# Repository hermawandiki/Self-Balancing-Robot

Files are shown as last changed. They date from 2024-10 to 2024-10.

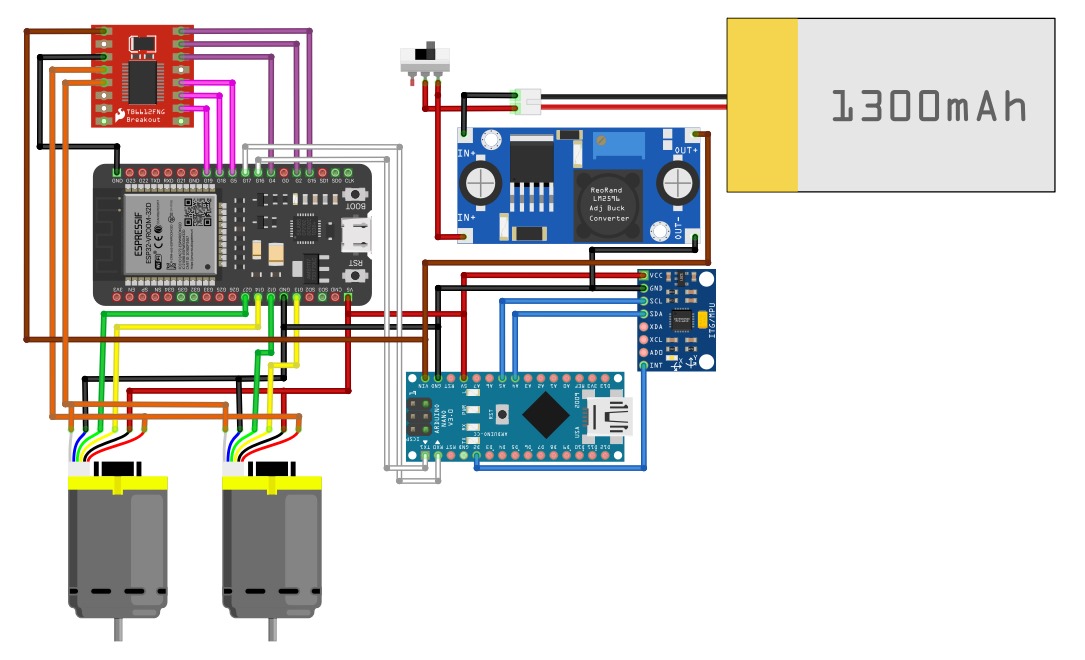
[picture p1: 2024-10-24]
Hardware/WhatsApp Image 2024-08-28 at 14.37.04_eb7606b8.jpg

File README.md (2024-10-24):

# Self-Balancing-Robot

Diki Hermawan - 4122600037
****
Mata Kuliah : Proyek Robotika
****
Dosen Pengampu : Eko Henfri Binugroho, S. S.T., M. Eng.
****
Semester 5 - Teknik Mekatronika

Politeknik Elektronika Negeri Surabaya

2024

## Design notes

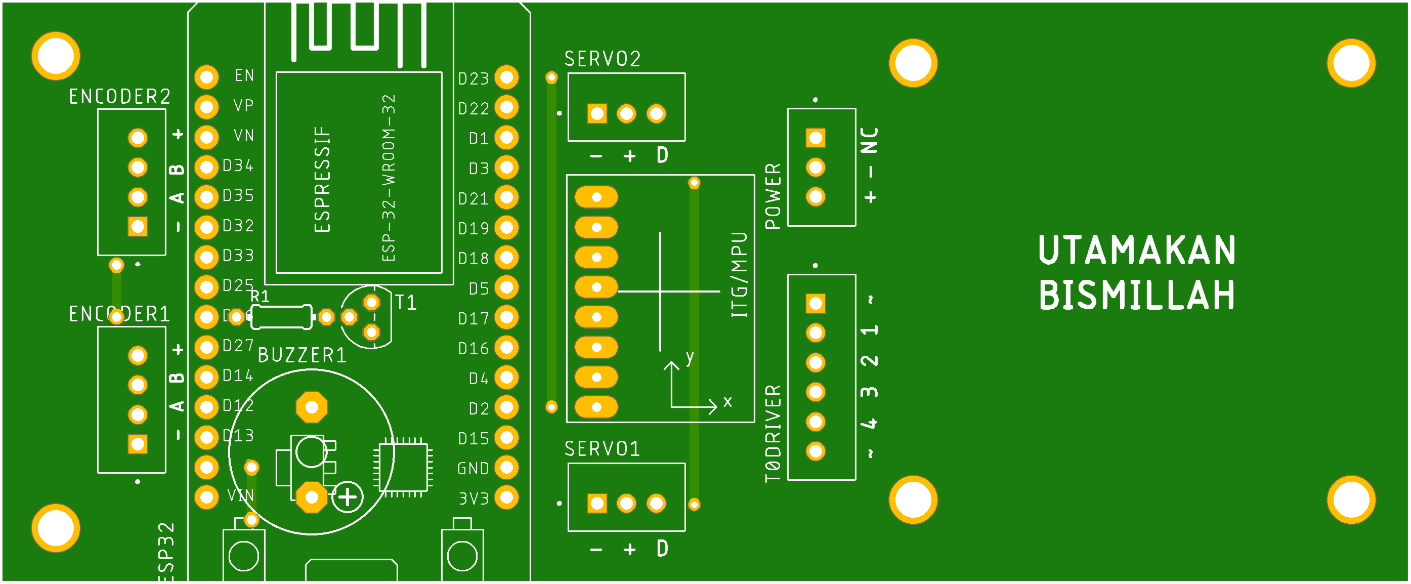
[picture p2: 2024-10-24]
Hardware/_Top.png

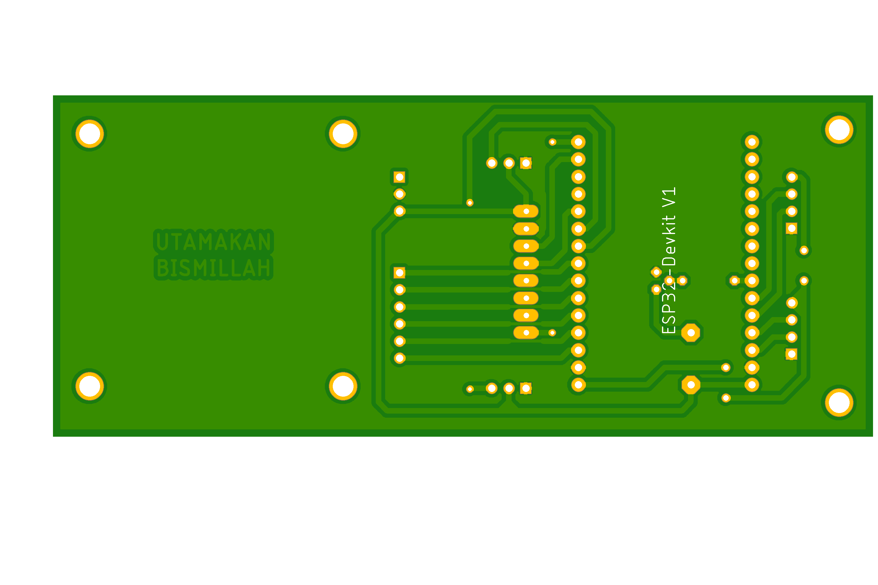
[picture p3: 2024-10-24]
Hardware/Bottom.png

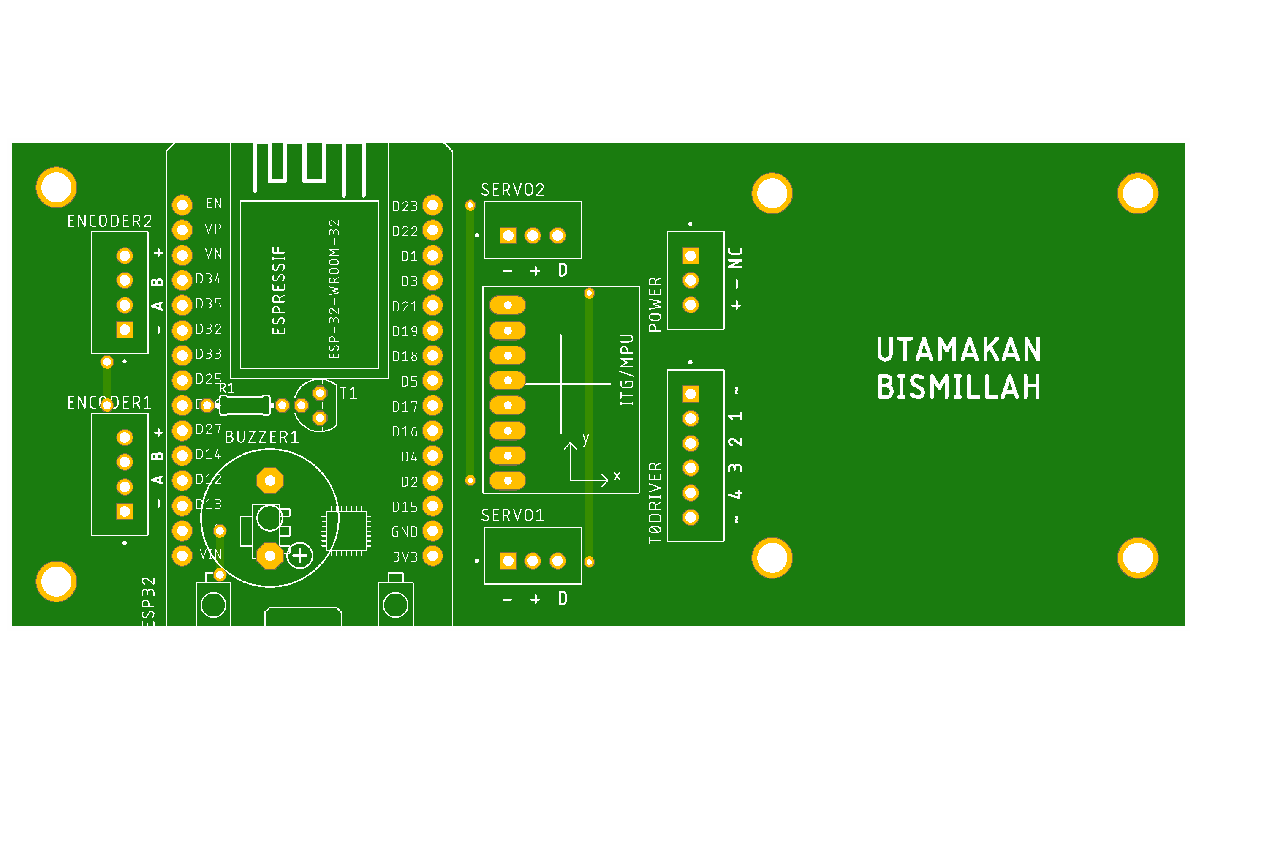
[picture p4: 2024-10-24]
Hardware/Top.png

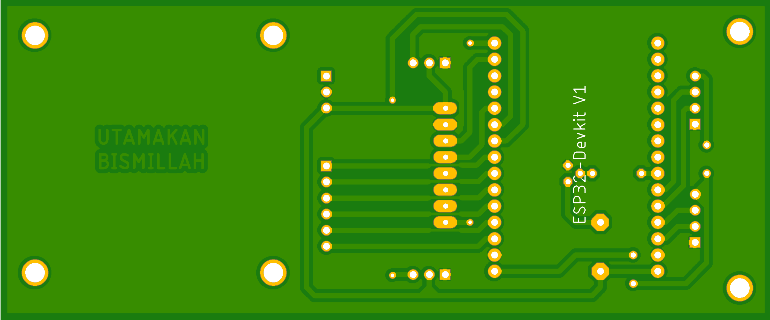
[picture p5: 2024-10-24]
Hardware/_Bottom.png

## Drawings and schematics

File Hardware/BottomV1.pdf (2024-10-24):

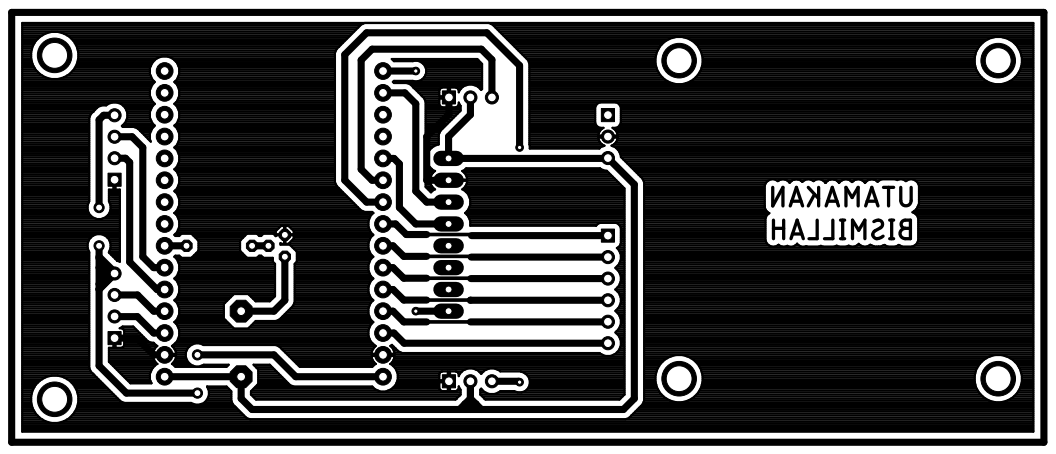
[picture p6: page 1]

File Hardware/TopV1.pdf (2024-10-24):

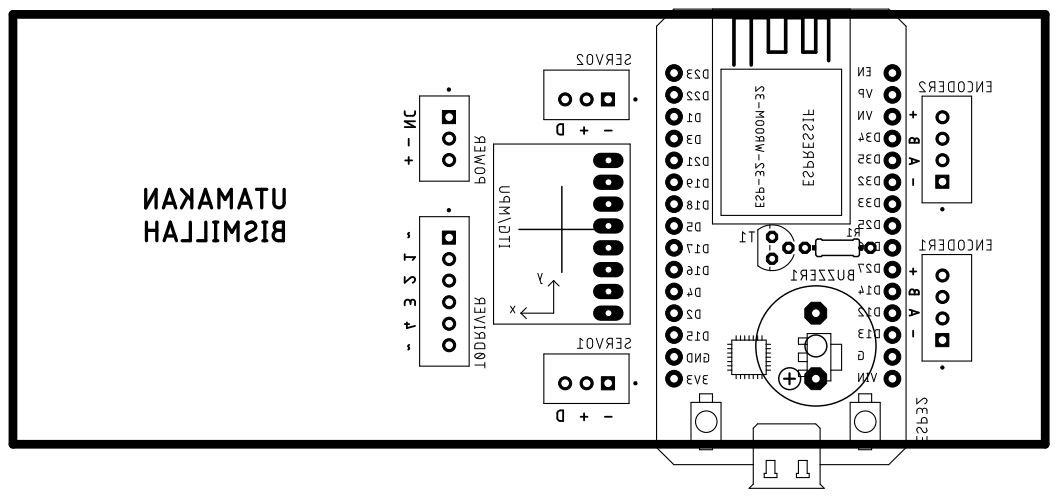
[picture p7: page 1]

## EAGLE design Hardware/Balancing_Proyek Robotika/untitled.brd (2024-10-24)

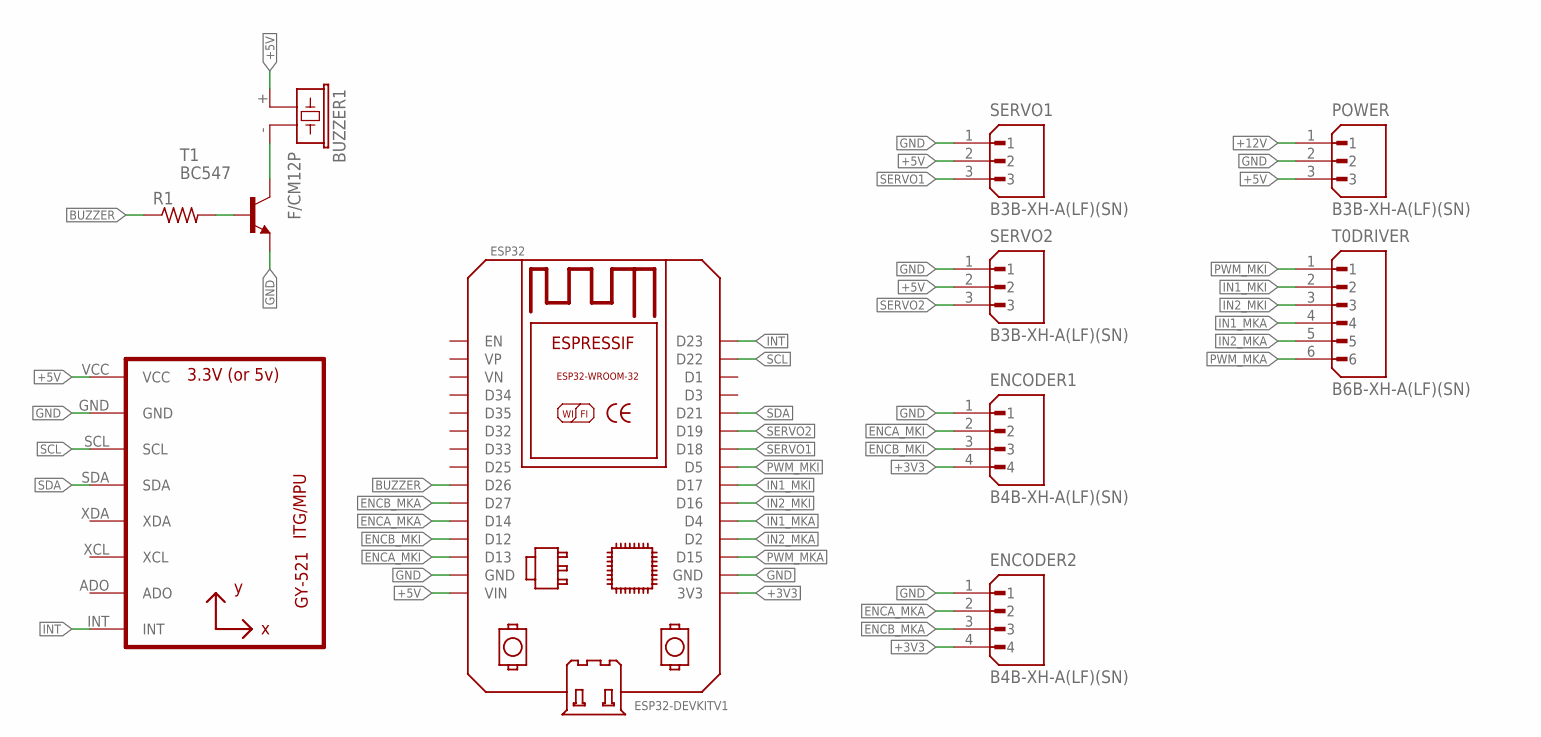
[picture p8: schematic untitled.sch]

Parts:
BUZZER1: F/CM12P
ENCODER1, ENCODER2: B4B-XH-A(LF)(SN); JST_B4B-XH-A(LF)(SN)
ESP32: ESP32DEVKITV1; ESP32-DEVKITV1
POWER: B3B-XH-A(LF)(SN); JST_B3B-XH-A(LF)(SN)
R1: R-US_0204/7; 0204/7
SERVO1, SERVO2: B3B-XH-A(LF)(SN); JST_B3B-XH-A(LF)(SN)
T0DRIVER: B6B-XH-A(LF)(SN); JST_B6B-XH-A(LF)(SN)
T1: BC547; TO92
U2: GY-521MPU6050; GY-521

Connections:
+3V3: ENCODER1.4, ENCODER2.4, ESP32.3V3
+5V: BUZZER1.+ (1), ESP32.VIN, POWER.3, SERVO1.2, SERVO2.2, U2.VCC
+12V: POWER.1
BUZZER: ESP32.D26, R1.1
ENCA_MKA: ENCODER2.2, ESP32.D14
ENCA_MKI: ENCODER1.2, ESP32.D13
ENCB_MKA: ENCODER2.3, ESP32.D27
ENCB_MKI: ENCODER1.3, ESP32.D12
GND: ENCODER1.1, ENCODER2.1, ESP32.GND, ESP32.GND@1 (GND), POWER.2, SERVO1.1, SERVO2.1, T1.1 (E), U2.GND
IN1_MKA: ESP32.D4, T0DRIVER.4
IN1_MKI: ESP32.D17, T0DRIVER.2
IN2_MKA: ESP32.D2, T0DRIVER.5
IN2_MKI: ESP32.D16, T0DRIVER.3
INT: ESP32.D23, U2.INT
unnamed: BUZZER1.- (2), T1.3 (C)
unnamed: R1.2, T1.2 (B)
PWM_MKA: ESP32.D15, T0DRIVER.6
PWM_MKI: ESP32.D5, T0DRIVER.1
SCL: ESP32.D22, U2.SCL
SDA: ESP32.D21, U2.SDA
SERVO1: ESP32.D18, SERVO1.3
SERVO2: ESP32.D19, SERVO2.3

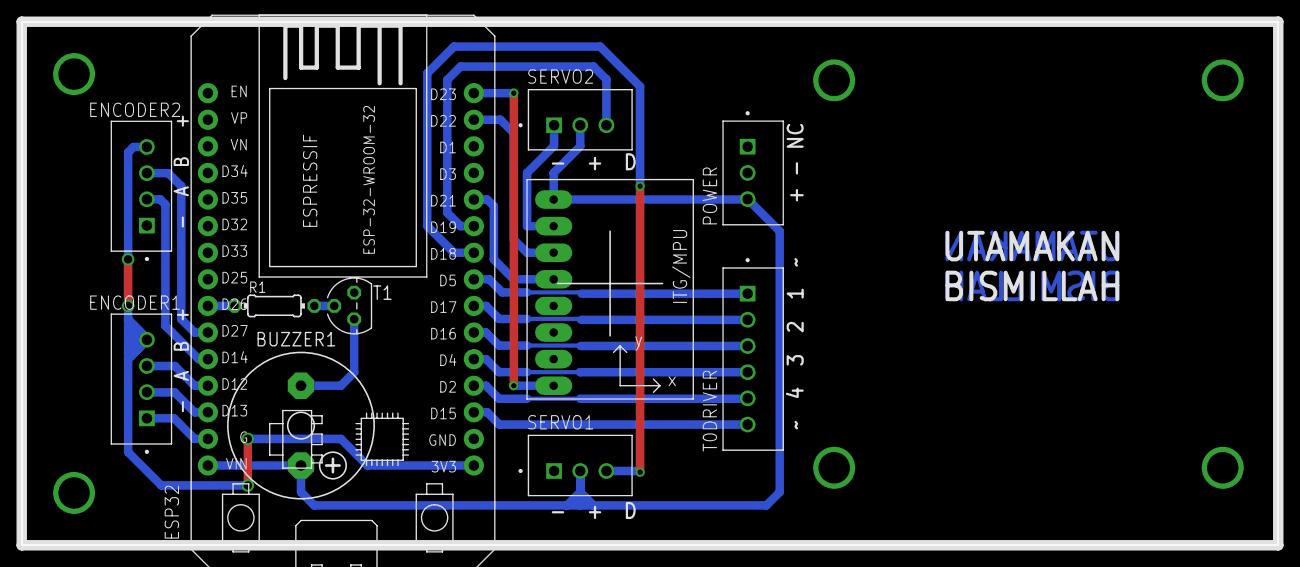
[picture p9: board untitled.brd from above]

Board: 2 copper layers, 120.0 x 50.0 mm, 11 parts (0 on the bottom side), 21 nets.

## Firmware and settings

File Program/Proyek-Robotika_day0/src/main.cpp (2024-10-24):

#include <Arduino.h>
#include <BluetoothSerial.h>
#include <ESP32Servo.h>
#include <ESP32Encoder.h>
#include "I2Cdev.h"
#include "MPU6050_6Axis_MotionApps20.h"
#include "Wire.h"
#include "math.h"

#define ENCA_MKa 13
#define ENCB_MKa 12
#define ENCA_MKi 14
#define ENCB_MKi 27

#define IN1_MKa 15
#define IN2_MKa 2
#define PWM_MKa 4

#define IN1_MKi 16
#define IN2_MKi 17
#define PWM_MKi 5

#define ServoPin1 18
#define ServoPin2 19

BluetoothSerial blutut;
MPU6050 mpu;
Servo servo1, servo2;
ESP32Encoder encoder_MKa;
ESP32Encoder encoder_MKi;

const int PWM_CHANNEL_MKa = 2;
const int PWM_CHANNEL_MKi = 3;
const int PWM_FREQ = 30000;
const int PWM_RESOLUTION = 8;
const int PWM_MAX_DUTY = (int)(pow(2, PWM_RESOLUTION) - 1);

#define INTERRUPT_PIN 23
#define LED_PIN 2
bool blinkState = false;

bool dmpReady = false;
uint8_t mpuIntStatus;
uint8_t devStatus;
uint16_t packetSize;
uint16_t fifoCount;
uint8_t fifoBuffer[64];

Quaternion q;
VectorInt16 aa;
VectorInt16 aaReal;
VectorInt16 aaWorld;
VectorFloat gravity;

float euler[3];
float ypr[3];
uint8_t teapotPacket[14] = { '$', 0x02, 0, 0, 0, 0, 0, 0, 0, 0, 0x00, 0x00, '\r', '\n' };
volatile bool mpuInterrupt = false;
void dmpDataReady() {
    mpuInterrupt = true;
}

unsigned int Yaw, Pitch, Roll;
char buffRx;
bool flag = 0, konek = 0;
long lastTime = 0;
uint8_t step = 0;

void motor(int pwm1, int pwm2){
  if(pwm1>0){
    digitalWrite(IN1_MKi, HIGH);
    digitalWrite(IN2_MKi, LOW);
  }else{
    digitalWrite(IN1_MKi, LOW);
    digitalWrite(IN2_MKi, HIGH);
  }

  if(pwm2>0){
    digitalWrite(IN1_MKa, HIGH);
    digitalWrite(IN2_MKa, LOW);
  }else{
    digitalWrite(IN1_MKa, LOW);
    digitalWrite(IN2_MKa, HIGH);
  }

  pwm1 = constrain(abs(pwm1) + 10, 10, 255);
  pwm2 = constrain(abs(pwm2) + 10, 10, 255);
  
  ledcWrite(PWM_CHANNEL_MKi, pwm1);
  ledcWrite(PWM_CHANNEL_MKa, pwm2);
}

void setup() {
  Wire.begin();
  Wire.setClock(400000);
  Serial.begin(115200);
  blutut.begin("Robot Dinasti");

  mpu.initialize();
  pinMode(INTERRUPT_PIN, INPUT);
  devStatus = mpu.dmpInitialize();
  mpu.setXGyroOffset(220);
  mpu.setYGyroOffset(76);
  mpu.setZGyroOffset(-85);
  mpu.setZAccelOffset(1788);

  if(devStatus == 0){
    mpu.CalibrateAccel(6);
    mpu.CalibrateGyro(6);
    mpu.PrintActiveOffsets();
    mpu.setDMPEnabled(true);
    attachInterrupt(digitalPinToInterrupt(INTERRUPT_PIN), dmpDataReady, RISING);
    mpuIntStatus = mpu.getIntStatus();
    dmpReady = true;
    packetSize = mpu.dmpGetFIFOPacketSize();
  } else{
    // ga lapo-lapo
  }

  pinMode(LED_PIN, OUTPUT);

  ESP32PWM::allocateTimer(0);
  ESP32PWM::allocateTimer(1);
  servo1.setPeriodHertz(50);
  servo1.attach(ServoPin1, 500, 2500);
  servo2.setPeriodHertz(50);
  servo2.attach(ServoPin2, 500, 2500);
  
  pinMode(IN1_MKa, OUTPUT);
  pinMode(IN2_MKa, OUTPUT);
  pinMode(IN1_MKi, OUTPUT);
  pinMode(IN2_MKi, OUTPUT);
  ledcSetup(PWM_CHANNEL_MKa, PWM_FREQ, PWM_RESOLUTION);
  ledcSetup(PWM_CHANNEL_MKi, PWM_FREQ, PWM_RESOLUTION);
  ledcAttachPin(PWM_MKa, PWM_CHANNEL_MKa);
  ledcAttachPin(PWM_MKi, PWM_CHANNEL_MKi);

  step = 1;  
}

void loop() {
  if(!dmpReady) return;
  while (!mpuInterrupt && fifoCount < packetSize) {
    if (mpuInterrupt && fifoCount < packetSize) {
      fifoCount = mpu.getFIFOCount();
    }
  }
  mpuInterrupt = false;
  mpuIntStatus = mpu.getIntStatus();
  fifoCount = mpu.getFIFOCount();
  if (fifoCount < packetSize) {}
  else if ((mpuIntStatus & (0x01 << MPU6050_INTERRUPT_FIFO_OFLOW_BIT)) || fifoCount >= 1024) {
    mpu.resetFIFO();
  }
  else if (mpuIntStatus & (0x01 << MPU6050_INTERRUPT_DMP_INT_BIT)) {
    while (fifoCount >= packetSize) {
      mpu.getFIFOBytes(fifoBuffer, packetSize);
      fifoCount -= packetSize;
    }

    mpu.dmpGetQuaternion(&q, fifoBuffer);
    mpu.dmpGetGravity(&gravity, &q);
    mpu.dmpGetYawPitchRoll(ypr, &q, &gravity);

    Roll  = (int)(((ypr[2] * 180 / M_PI) + 180.0) + 0.5);
    Pitch = (int)(((ypr[1] * 180 / M_PI) + 180.0) + 0.5);
    Yaw   = (int)(((ypr[0] * 180 / M_PI) + 180.0) + 0.5);

    // blinkState = !blinkState;
    // digitalWrite(LED_PIN, blinkState);
  }

  // ==================================================================== USER CODE BEGIN HERE ====================================================================
  
  Serial.print("Yaw: ");
  Serial.print(Yaw);
  Serial.print(" | Pitch: ");
  Serial.print(Pitch);
  Serial.print(" | Roll: ");
  Serial.println(Roll);

  // if(millis() - lastTime > 1000 && step == 1){
  //   servo1.write(0);
  //   servo2.write(0);
  //   ledcWrite(PWM_CHANNEL_MKi, 150);
  //   ledcWrite(PWM_CHANNEL_MKa, 150);
  //   digitalWrite(IN1_MKa, HIGH);
  //   digitalWrite(IN2_MKa, HIGH);
  //   digitalWrite(IN1_MKi, HIGH);
  //   digitalWrite(IN2_MKi, HIGH);
  //   digitalWrite(LED_PIN, HIGH);
  //   lastTime = millis();
  //   step = 2;
  // }
  // if(millis() - lastTime > 1000 && step == 2){
  //   servo1.write(180);
  //   servo2.write(180);
  //   ledcWrite(PWM_CHANNEL_MKi, 50);
  //   ledcWrite(PWM_CHANNEL_MKa, 50);
  //   digitalWrite(IN1_MKa, LOW);
  //   digitalWrite(IN2_MKa, LOW);
  //   digitalWrite(IN1_MKi, LOW);
  //   digitalWrite(IN2_MKi, LOW);
  //   digitalWrite(LED_PIN, LOW);
  //   lastTime = millis();
  //   step = 1;
  // }

  // ===================================================================== USER CODE END HERE =====================================================================

  // if(blutut.available()){
  //   buffRx = blutut.read();
  //   Serial.println(buffRx);
  // }

  // if(millis() - lastTime > 50){
  //   blutut.print(Yaw);
  //   blutut.print("|");
  //   blutut.print(Pitch);
  //   blutut.print("|");
  //   blutut.print(Roll);
  //   blutut.println("|");
  //   lastTime = millis();
  // }

  // if(blutut.connected() && konek==0){
  //   blutut.println("Enter pin to start!");
  //   konek = 1;
  // }
  // if(!blutut.connected()){
  //   konek = 0;
  //   flag = 0;
  // }

  // if(blutut.available()){
  //   buffRx = blutut.read();
  //   Serial.println(buffRx);
  //   if(buffRx == '~') {
  //     blutut.println("Started...");
  //     flag = 1;
  //   }else {
  //     flag = 0;
  //     blutut.println("Can't start, try again!");
  //   }
  // }
  
  // while(flag){
  //   if(blutut.available()){
  //     buffRx = blutut.read();
  //     Serial.println(buffRx);
  //     if(buffRx == '`') {
  //       blutut.println("Stopped...");
  //       flag = 0;
  //     }
  //   }
  //   if(!blutut.connected()){
  //     konek = 0;
  //     flag = 0;
  //   }
    
  //   // code begin here
  //   if(millis() - lastTime > 1000){
  //     blutut.println("Balancing...");
  //     lastTime = millis();
  //   }
  //   // code end here
  // }
}

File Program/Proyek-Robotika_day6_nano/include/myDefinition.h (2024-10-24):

#ifndef __MYDEFINITION_H__
#define __MYDEFINITION_H__

#include <Arduino.h>

#define DEBUG 0

#if DEBUG == 0
#define debug(x) monitor.print(x);
#define debugln(x) monitor.println(x);
#else
#define debug(x)
#define debugln(x)
#endif

// PID
#define KpPitch 17.0  // 10 // 16 // 16 // 16
#define KdPitch 0.8  // 0.01 // 0.7 // 0.9 / 0.7
#define KiPitch 194.5  // 30 // 77 // 95 // 153

#define KpYaw 14.0
#define KdYaw 0.3
#define KiYaw 20.02

#define KpPos 0.0
#define KdPos 0.0
#define KiPos 0.0

// Motor Driver
#define PWM_MKI 9
#define IN1_MKI A3
#define IN2_MKI A2
#define IN1_MKA A1
#define IN2_MKA A0
#define PWM_MKA 10

// Serial Communication
#define RX_PIN_BT 0
#define TX_PIN_BT 1
#define RX_MONITOR 11
#define TX_MONITOR 12

// MPU6050
#define INT_PIN 4

// Encoder
#define ENCA_MKI 2
#define ENCB_MKI 7
#define ENCA_MKA 3
#define ENCB_MKA 8

// Servo
#define SERVO1_PIN 5
#define SERVO2_PIN 6

// Buzzer
#define BUZZER_PIN 13
#define BuzzOn digitalWrite(BUZZER_PIN, HIGH)
#define BuzzOff digitalWrite(BUZZER_PIN, LOW)
#define BuzzTit(y) {for(uint8_t ii=0; ii<y; ii++){BuzzOn; delay(70); BuzzOff; delay(70);}}

// Global Variable
extern uint8_t lastStateA1, lastStateB1, lastStateA2, lastStateB2;
extern volatile int encoderM1, encoderM2;
extern double spPitch, spYaw;

// Function Prototype
extern void configIO();
extern void motor(int16_t pwm1, int16_t pwm2);
extern void handleEncMki();
extern void handleEncMka();

#endif

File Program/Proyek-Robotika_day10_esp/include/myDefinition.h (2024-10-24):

#ifndef __MYDEFINITION_H__
#define __MYDEFINITION_H__

#include <Arduino.h>

#define DEBUG 1

#if DEBUG == 1
#define debug(x) Serial.print(x);
#define debugln(x) Serial.println(x);
#else
#define debug(x)
#define debugln(x)
#endif

// PID
const double KpPitch = 17.0;  // 10 // 16 // 16 // 16
const double KdPitch = 0.8;  // 0.01 // 0.7 // 0.9 / 0.7
const double KiPitch = 150.5;  // 30 // 77 // 95 // 153

const double KpYaw = 14.0;
const double KdYaw = 0.3;
const double KiYaw = 20.02;

// Motor Driver
#define PWM_MKI 15
#define IN1_MKI 2
#define IN2_MKI 4
#define IN1_MKA 16
#define IN2_MKA 17
#define PWM_MKA 5

#define PWM_MKI_CHANNEL 0
#define PWM_MKA_CHANNEL 1

// MPU6050
#define INT_PIN 23

// Encoder
#define ENCA_MKI 13
#define ENCB_MKI 25 // 12
#define ENCA_MKA 33 // 14
#define ENCB_MKA 27

// Servo
#define SERVO1_PIN 18
#define SERVO2_PIN 19

// Buzzer
#define BUZZER_PIN 26
#define BuzzOn digitalWrite(BUZZER_PIN, HIGH)
#define BuzzOff digitalWrite(BUZZER_PIN, LOW)
#define BuzzTit(y) {for(uint8_t ii=0; ii<y; ii++){BuzzOn; delay(70); BuzzOff; delay(70);}}

// Global Variable
extern uint8_t lastStateA1, lastStateB1, lastStateA2, lastStateB2;
extern volatile long encoderM1, encoderM2;

// Function Prototype
extern void configIO();
extern void motor(int16_t pwm1, int16_t pwm2);
extern void handleEncMki();
extern void handleEncMka();

#endif

////// Recommended servo pins include 2,4,12-19,21-23,25-27,32-33
/*
** ledc: 0  => Group: 0, Channel: 0, Timer: 0
** ledc: 1  => Group: 0, Channel: 1, Timer: 0
** ledc: 2  => Group: 0, Channel: 2, Timer: 1
** ledc: 3  => Group: 0, Channel: 3, Timer: 1
** ledc: 4  => Group: 0, Channel: 4, Timer: 2
** ledc: 5  => Group: 0, Channel: 5, Timer: 2
** ledc: 6  => Group: 0, Channel: 6, Timer: 3
** ledc: 7  => Group: 0, Channel: 7, Timer: 3
** ledc: 8  => Group: 1, Channel: 8, Timer: 0
** ledc: 9  => Group: 1, Channel: 9, Timer: 0
** ledc: 10 => Group: 1, Channel: 10, Timer: 1
** ledc: 11 => Group: 1, Channel: 11, Timer: 1
** ledc: 12 => Group: 1, Channel: 12, Timer: 2
** ledc: 13 => Group: 1, Channel: 13, Timer: 2
** ledc: 14 => Group: 1, Channel: 14, Timer: 3
** ledc: 15 => Group: 1, Channel: 15, Timer: 3
*/

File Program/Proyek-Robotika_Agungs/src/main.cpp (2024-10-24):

#include <Arduino.h>
#include "PID_v1.h"
#include "MPU6050_6Axis_MotionApps20.h"
#include "Wire.h"
#include "ESP32Encoder.h"

MPU6050 mpu;
bool blinkState = false;
bool dmpReady = false;
uint8_t mpuIntStatus;
uint8_t devStatus;
uint16_t packetSize;
uint16_t fifoCount;
uint8_t fifoBuffer[64];
Quaternion q;
VectorFloat gravity;
float euler[3];
float ypr[3];
volatile bool mpuInterrupt = false;
void dmpDataReady() {
  mpuInterrupt = true;
}
int Yaw, Pitch, Roll;

double originalSetpoint = 180.0;
double setpointPitch = originalSetpoint;
double setpointYaw = originalSetpoint;
double movingAngleOffset = 0.1;
double inputPitch, outputPitch, inputYaw, outputYaw;

double KpPitch = 17; // 10 // 16 // 16 // 16
double KdPitch = 0.8; // 0.01 // 0.7 // 0.9 / 0.7
double KiPitch = 194.5; // 30 // 77 // 95 // 153
PID pidPitch(&inputPitch, &outputPitch, &setpointPitch, KpPitch, KiPitch, KdPitch, DIRECT);
double KpYaw = 14;
double KdYaw = 0.3;
double KiYaw = 20.02;
PID pidYaw(&inputYaw, &outputYaw, &setpointYaw, KpYaw, KiYaw, KdYaw, DIRECT);

ESP32Encoder encM1, encM2;
uint8_t pinMotor[] = {15, 2, 4, 16, 17, 5};
void motor(int16_t pwm1, int16_t pwm2){
  if(pwm1>0){
    digitalWrite(2, HIGH);
    digitalWrite(4, LOW);
  }else{
    digitalWrite(2, LOW);
    digitalWrite(4, HIGH);
  }

  if(pwm2>0){
    digitalWrite(16, LOW);
    digitalWrite(17, HIGH);
  }else{
    digitalWrite(16, HIGH);
    digitalWrite(17, LOW);
  }

  pwm1 = constrain(abs(pwm1), 0, 255); // 0
  pwm2 = constrain(abs(pwm2)+10, 10, 255); // 10
  
  ledcWrite(0, pwm1);
  ledcWrite(1, pwm2);
}
//
uint8_t i;

void setup(){
  Wire.begin();
  Wire.setClock(400000);
  Serial.begin(9600);
  for(int i=0; i<6; i++){
    pinMode(pinMotor[i], OUTPUT);
  }

  ledcSetup(0, 30000, 8);
  ledcSetup(1, 30000, 8);
  ledcAttachPin(15, 0);
  ledcAttachPin(5, 1);

  mpu.initialize();
  pinMode(23, INPUT);
  devStatus = mpu.dmpInitialize();
  mpu.setXGyroOffset(220);
  mpu.setYGyroOffset(76);
  mpu.setZGyroOffset(-85);
  mpu.setZAccelOffset(1788);

  if(devStatus == 0){
    mpu.CalibrateAccel(6);
    mpu.CalibrateGyro(6);
    mpu.PrintActiveOffsets();
    mpu.setDMPEnabled(true);
    attachInterrupt(digitalPinToInterrupt(23), dmpDataReady, RISING);
    mpuIntStatus = mpu.getIntStatus();
    dmpReady = true;
    packetSize = mpu.dmpGetFIFOPacketSize();

    pidPitch.SetMode(AUTOMATIC);
    pidPitch.SetSampleTime(10);
    pidPitch.SetOutputLimits(-255, 255);
    pidYaw.SetMode(AUTOMATIC);
    pidYaw.SetSampleTime(10);
    pidYaw.SetOutputLimits(-100, 100);
  } else{
    // ga lapo-lapo
  }

  pinMode(26, OUTPUT);
  digitalWrite(26, LOW);
  for(uint8_t i=0; i<6;i++){
    digitalWrite(26, !digitalRead(26));
    delay(70);
  }
  
  encM1.attachFullQuad(13, 12);
  encM2.attachFullQuad(14, 27);
}

void loop(){
  if (!dmpReady) return;
  if (mpu.dmpGetCurrentFIFOPacket(fifoBuffer)) {
    mpu.dmpGetQuaternion(&q, fifoBuffer);
    mpu.dmpGetGravity(&gravity, &q);
    mpu.dmpGetYawPitchRoll(ypr, &q, &gravity);

    // Pitch = (int)(((ypr[2] * 180 / M_PI) + 180.0) + 0.5);  // depan++ belakang--
    // Roll = (int)(((ypr[1] * 180 / M_PI) + 180.0) + 0.5);  // kanan++ kiri--
    // Yaw = (int)(((ypr[0] * 180 / M_PI) + 180.0) + 0.5); // kanan++ kiri--

    // Serial.print(Yaw);
    // Serial.print('\t');
    // Serial.print(Pitch);
    // Serial.print('\t');
    // Serial.print(Roll);
    // Serial.print('\n');

    inputPitch = (ypr[2] * 180 / M_PI + 180) + 0.5;
    inputYaw = (ypr[0] * 180 / M_PI + 180) + 0.5;
  }
  pidPitch.Compute();
  pidYaw.Compute();
  motor(outputPitch - outputYaw, outputPitch + outputYaw);
  if(inputPitch<=180 && inputPitch>=179.7) digitalWrite(26, HIGH);
  else digitalWrite(26, LOW);

  // Serial.print(encM1.getCount());
  // Serial.print("  ");
  // Serial.println(encM2.getCount());
}

////// Recommended servo pins include 2,4,12-19,21-23,25-27,32-33
/*
** ledc: 0  => Group: 0, Channel: 0, Timer: 0
** ledc: 1  => Group: 0, Channel: 1, Timer: 0
** ledc: 2  => Group: 0, Channel: 2, Timer: 1
** ledc: 3  => Group: 0, Channel: 3, Timer: 1
** ledc: 4  => Group: 0, Channel: 4, Timer: 2
** ledc: 5  => Group: 0, Channel: 5, Timer: 2
** ledc: 6  => Group: 0, Channel: 6, Timer: 3
** ledc: 7  => Group: 0, Channel: 7, Timer: 3
** ledc: 8  => Group: 1, Channel: 8, Timer: 0
** ledc: 9  => Group: 1, Channel: 9, Timer: 0
** ledc: 10 => Group: 1, Channel: 10, Timer: 1
** ledc: 11 => Group: 1, Channel: 11, Timer: 1
** ledc: 12 => Group: 1, Channel: 12, Timer: 2
** ledc: 13 => Group: 1, Channel: 13, Timer: 2
** ledc: 14 => Group: 1, Channel: 14, Timer: 3
** ledc: 15 => Group: 1, Channel: 15, Timer: 3
*/
